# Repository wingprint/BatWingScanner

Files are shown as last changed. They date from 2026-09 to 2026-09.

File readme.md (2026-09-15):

# Bat wing scanner for WingPrint images
This repository contains the code and assembly instructions for the bat wing scanner as described in our WingPrint publication.

Project Website: [https://wingprint.github.io/](https://wingprint.github.io/)

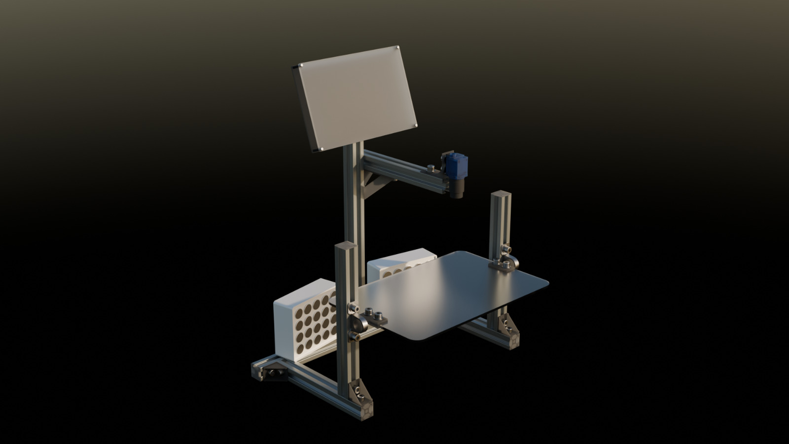
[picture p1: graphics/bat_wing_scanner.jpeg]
Bat wing scanner


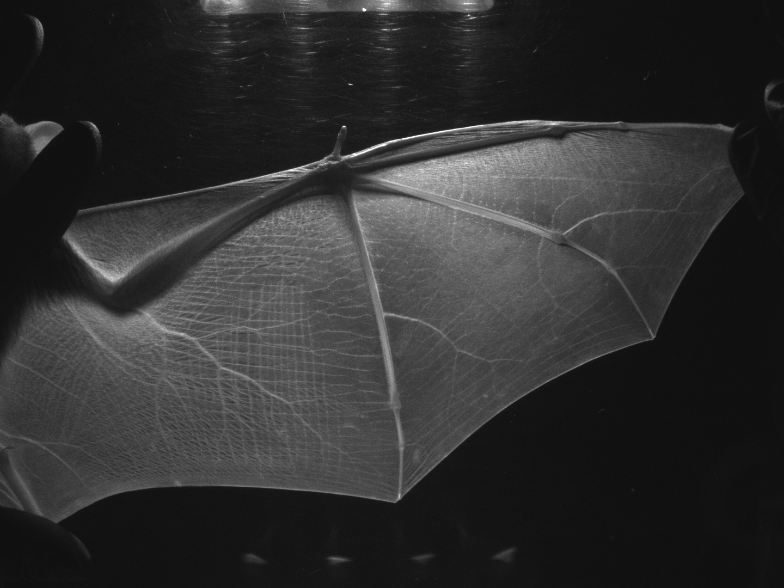
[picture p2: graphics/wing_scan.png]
Wing scan


## Software Installation
This guide describes how to set up the bat wing scanner software on different platforms.

### Platforms
The bat scanner software runs on Linux, Windows (and potentially Mac OS if camera drivers are available). Pi mode can be can be enabled by setting `pi: True` in the configuration file `config.yaml`. This will e.g. enable GPIO features.

We have tested the software on Raspberry Pi 3B+, 4B, and 5 models.

### Cameras
The software works with both industrial cameras and other off-the-shelf cameras like webcams.

If an industrial camera that supports the *GenICam* standard is detected, then that one is used. Otherwise the software tries to pick the next best available camera (e.g. a webcam).

If no camera is detected at all, the software will still run, but show unexpected behaviour in some areas.

### Installation on a Raspberry Pi 3/4/5
Download an image of a recent Raspberry Pi OS 64-bit including the Raspberry Pi Desktop. The following setup has been tested with the Raspberry Pi OS version based on Debian Trixie.

**Optional: Camera driver**

If you want to use an industrial camera that supports the *GenICam* standard, then install a *GenTL producer* from the camera manufacturer. Usually, the manufacturers provide either a complete SDK or a stand-alone GenTL producer.

In our case, we installed a stand-alone GenTL producer from *The Imaging Source* in the form of a Debian package:

`sudo apt install ./gen_tl_producer_arm64.deb`

Afterwards, edit the path to the CTI (Common Transport Interface) file of the driver in the `config.yaml` file. In our case the file is located at:

`cti_path: "/usr/lib/aarch64-linux-gnu/gentl/tis/libic4-gentl-u3v.cti"`

**Note:** The file needs to stay in its original location. Don't copy it somewhere else.

If you don't use an industrial camera, then you shouldn't need to install a camera driver.

**Setting up software framework**

First of all, you need to install some system-wide extensions for PyQT5:

`sudo apt install python3-pyqt5.qtmultimedia python3-pyqt5.qtsvg`

Now, create a Python virtual environment, but with system package access:

`python -m venv --system-site-packages .venv`

and activate it:

`source .venv/bin/activate`

Finally, you can install all necessary dependencies in your virtual environment:

`pip install -r requirements.txt`

**Provide a configuration**

Your `config.yaml` file should look similar to this at this point:

```
machine:
  name: 'Batscanner'
  pi: True
  port: 5000
  cti_path: "/usr/lib/aarch64-linux-gnu/gentl/tis/libic4-gentl-u3v.cti"
camera:
  preview_frame_rate: 30
```

**Launching the bat scanner software**

Run the program with:

`python main.py --production`

The *--production* switch enables fullscreen mode. Run the program without it if you are not on a Raspberry Pi or want to debug the program. In this case, the program will roughly scale to its intended target screen size.

You can access the webserver on the scanner under the address https://127.0.0.1:5000 or via the external IP address of your Raspberry Pi if it is part of a network.

The scan database and all images that you take will be stored inside the `<code_folder>/static/capture/<machine_name>` folder.

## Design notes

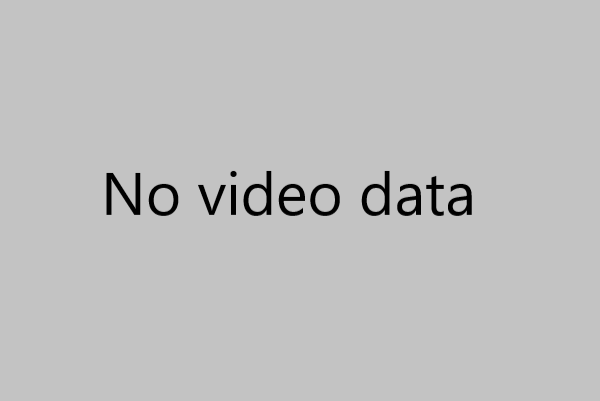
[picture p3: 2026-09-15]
code/graphics/no_video_data.png

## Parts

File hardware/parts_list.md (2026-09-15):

Frame
    aluminium profiles Bosch-type 20x20mm groove 6mm
        1x 530mm
        1x 450mm
        2x 300mm
        3x 250mm
    connectors
        6x Elbow Connector
        12x T-nuts
        12x M4x8mm screws or similar
    screen attachment
        2x M6x20mm screws
        4x M6 washers
        2x M6 wing nuts
        2x M3x10mm screws
        4x M3 washers
        2x M3 nuts
        2x M4x10mm screws
        2x M4 washers
    cantilever attachment
        4x M4x10mm screws
        4x M4 washers
    camera attachment
        2x M6x12mm screws
        2x M4x10mm screws
        2x M4 washers
    plate bearings
        2x Pedestal Bearings
        4x M4x10mm screws
    plate drive
        1x stepper motor 28BYJ-48
        1x motor driver board ULN2003
        1x synchronous wheel drive 20-60T-8B-6 with drivebelt
        6x M4x10mm screws
        6x M4 washers
Acrylic glass plate
    400mm x 250mm with rounded edges
    4x M4x20mm screws
Touchscreen
    Waveshare 10.1inch HDMI LCD
Computer
    1x Raspberry Pi 5 4GB
    1x KKSB Raspberry Pi 5 Case Aluminium Black
    4x M2x8mm screws
Camera
    1x The Imaging Source DMK 33UX273
    1x USB 3.0 Type A to Micro B
    1x Computar A4Z2812CS-MPIR lens
    1x Basler heat sink for ace 2 and racer 2 S (with custom screw holes)
Pedal
    1x Proxxon Footswitch FS

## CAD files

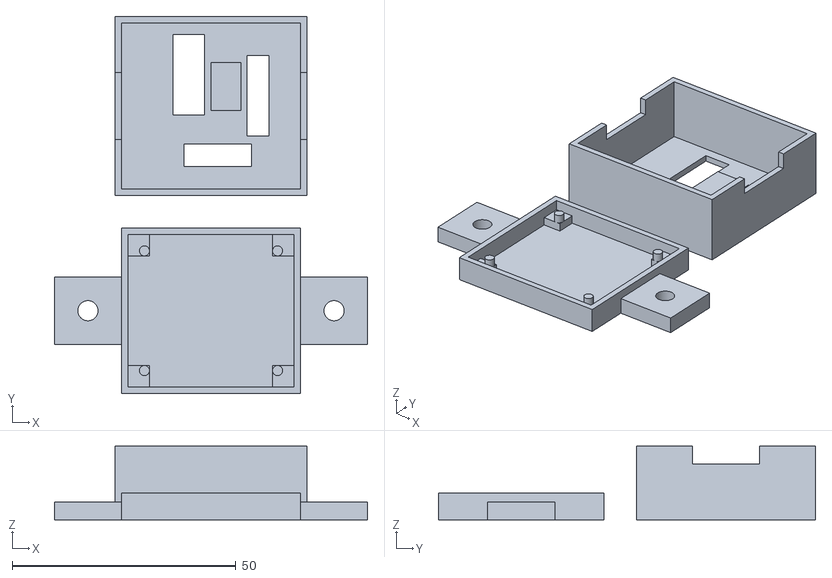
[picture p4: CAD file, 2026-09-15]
hardware/3D_Models/motor_driver_case.stl
70.0 x 84.2 x 16.5

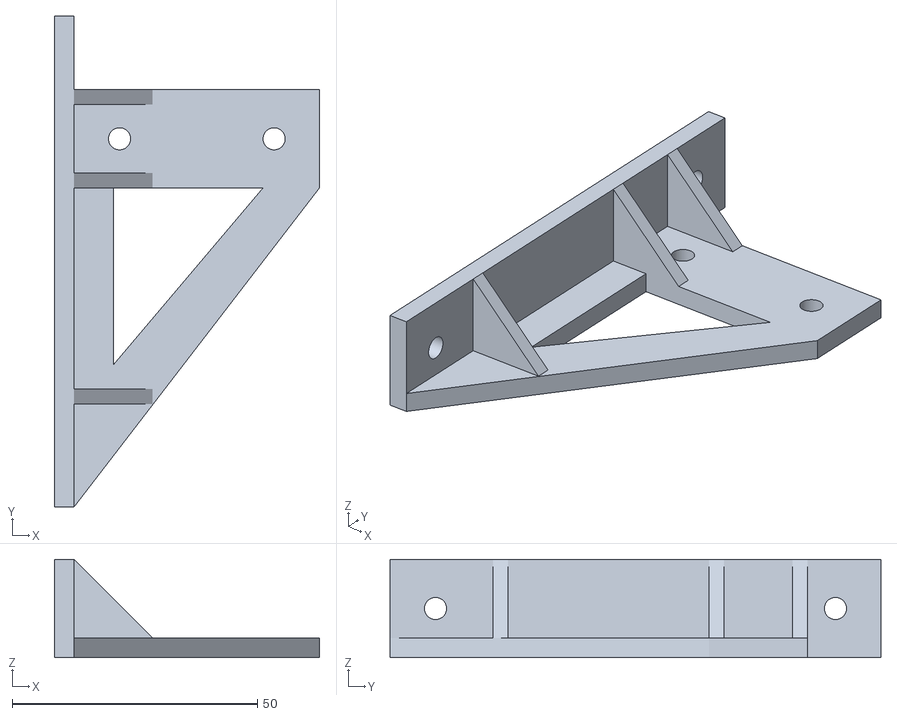
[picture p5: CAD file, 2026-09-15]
hardware/3D_Models/cantilever_attachment.stl
54.0 x 100.0 x 20.0

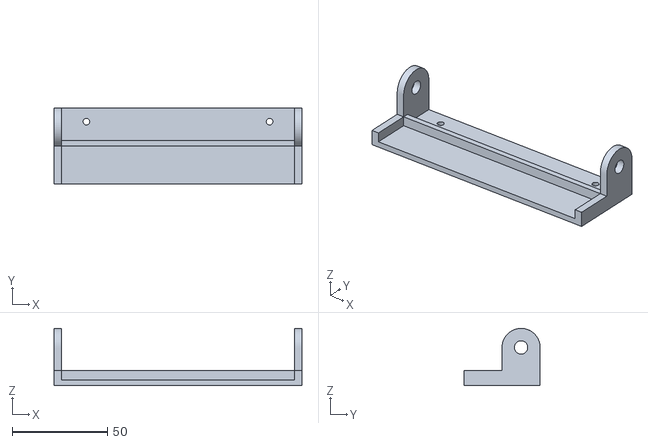
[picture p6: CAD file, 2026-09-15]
hardware/3D_Models/screen_attachment.stl
130.0 x 40.0 x 30.0

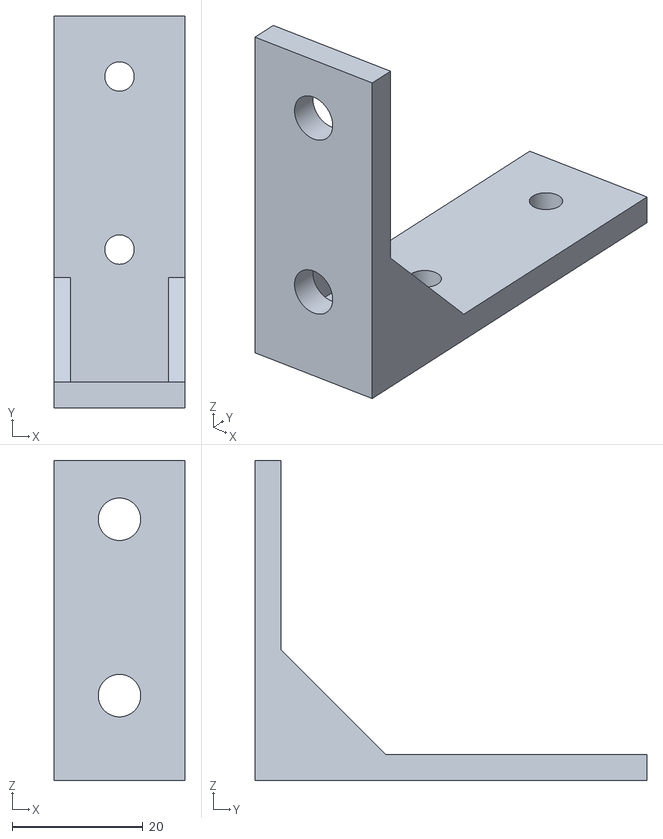
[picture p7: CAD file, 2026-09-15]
hardware/3D_Models/camera_holder_single.stl
20.0 x 60.0 x 49.0

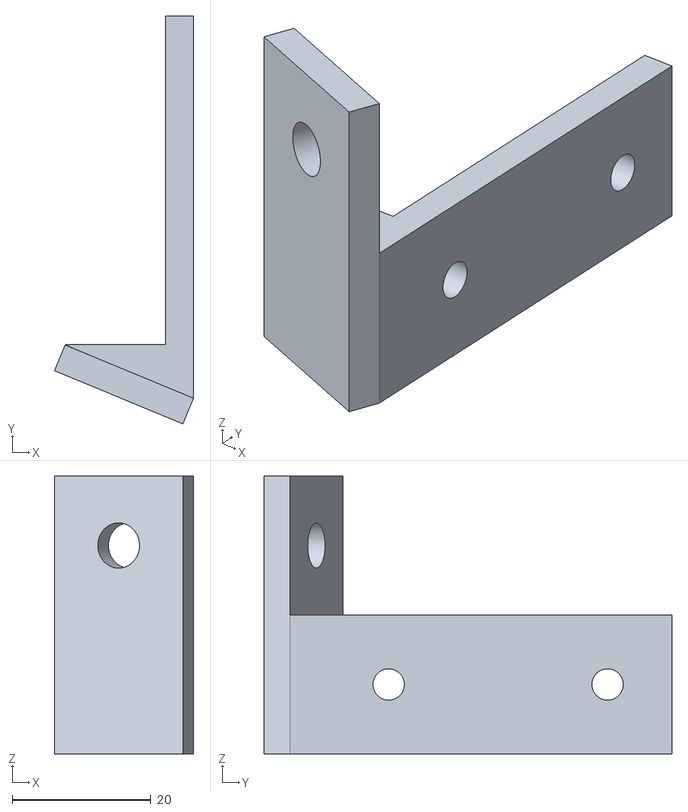
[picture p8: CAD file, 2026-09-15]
hardware/3D_Models/floodlight_holder.stl
20.0 x 58.7 x 40.0

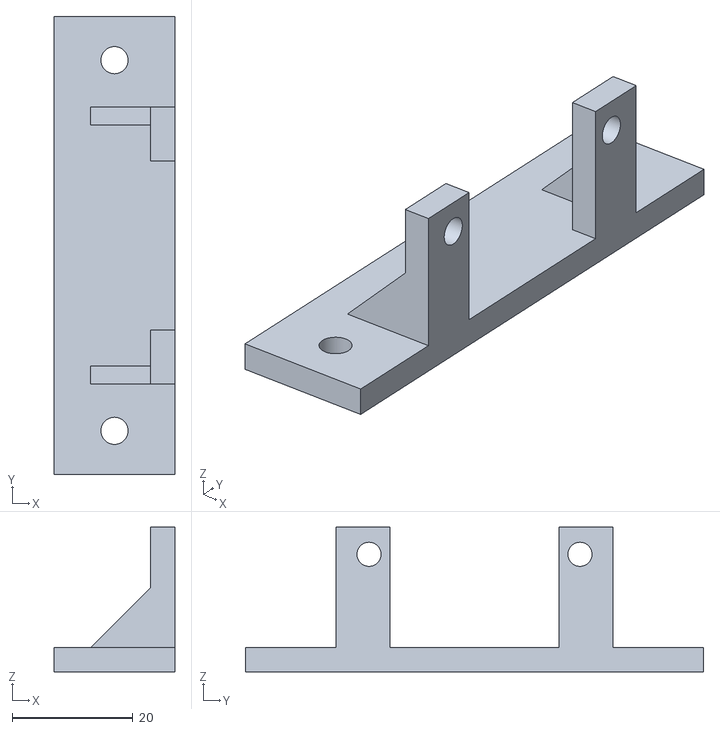
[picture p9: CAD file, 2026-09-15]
hardware/3D_Models/motor_holder.stl
20.0 x 76.0 x 24.0

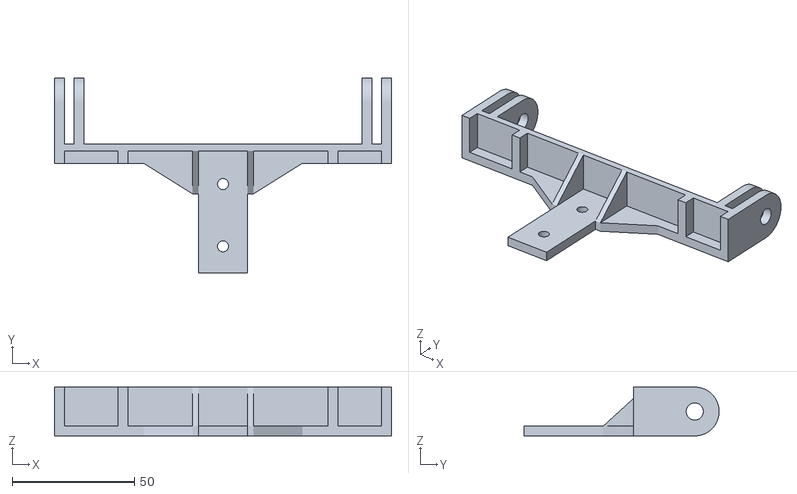
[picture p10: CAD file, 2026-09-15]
hardware/3D_Models/screen_holder.stl
138.0 x 80.0 x 20.0

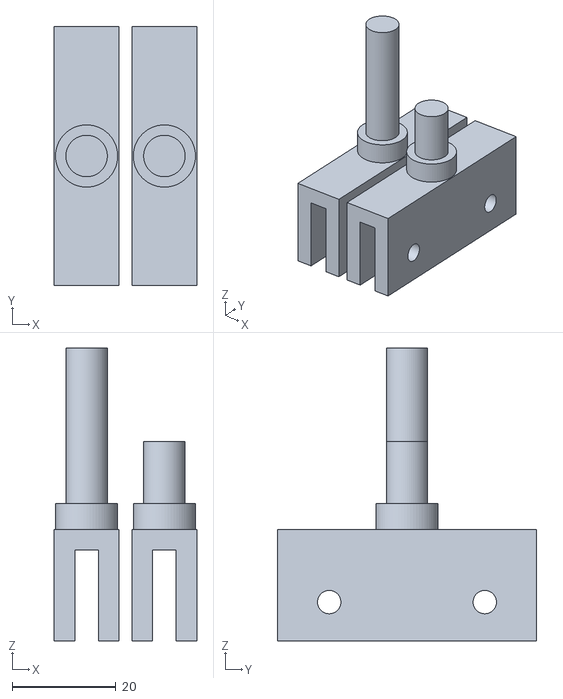
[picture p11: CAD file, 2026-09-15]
hardware/3D_Models/glass_plate_attachments.stl
27.5 x 50.0 x 56.5

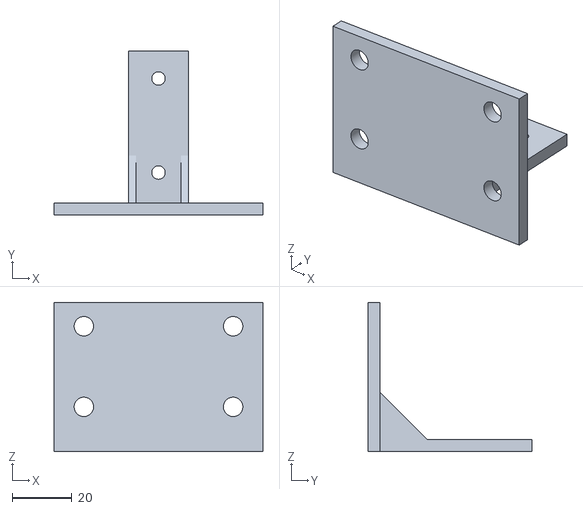
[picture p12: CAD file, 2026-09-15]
hardware/3D_Models/camera_holder_double.stl
70.0 x 55.0 x 50.0

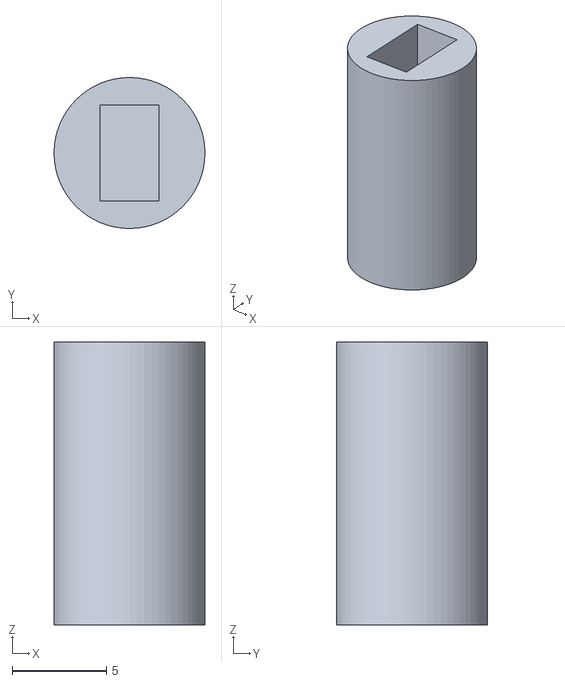
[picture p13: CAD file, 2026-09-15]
hardware/3D_Models/motor_axle.stl
8.00 x 8.00 x 15.0

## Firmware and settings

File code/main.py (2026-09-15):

import argparse
from functools import partial
import cv2
import glob
import numpy as np
import os
from pathlib import Path
import shutil
import time
import yaml
import sys

# Camera
from genicam.gentl import TimeoutException
from harvesters.core import Harvester
from harvesters.util.pfnc import mono_location_formats, rgb_formats, bgr_formats, rgba_formats, bgra_formats

# UI
from PyQt5.QtWidgets import *
from PyQt5.QtMultimedia import *
from PyQt5.QtMultimediaWidgets import *
from PyQt5.QtGui import QPixmap, QImage
from PyQt5.QtCore import Qt, QTimer, QEvent, QObject, QThread, pyqtSignal, pyqtSlot
import qdarktheme

import utils
import camUtils
import hwUtils
import translation

from batServer import ServerThread

from BatServerConnector import BatServerConnector

with open('config.yaml') as f:
    config = yaml.safe_load(f)

if config["machine"]["pi"]:
    from gpiozero import Button

class StepperWorker(QObject):
    finished = pyqtSignal()

    def __init__(self, direction, elevation):
        super(StepperWorker, self).__init__(None)

        self.direction = direction
        self.elevation = elevation

    @pyqtSlot()
    def run(self):
        if self.direction == 0:
            hwUtils.forward(self.elevation)
        else:
            hwUtils.backwards(self.elevation)

        self.finished.emit()

class SaveWorker(QObject):
    imagesSaved = pyqtSignal(Path)

    def __init__(self, images):
        super(SaveWorker, self).__init__(None)

        self.images = images

    @pyqtSlot()
    def run(self):
        folderPath = None

        for path, image in self.images:
            folderPath = Path(path).parent
            os.makedirs(folderPath, exist_ok=True)
            cv2.imwrite(path, image)
        
        self.imagesSaved.emit(folderPath)

class CaptureWorker(QObject):
    updateFeed = pyqtSignal(QImage)
    imageCaptured = pyqtSignal(np.ndarray, QImage)

    def __init__(self, imageAcquirer, cam):
        super(CaptureWorker, self).__init__(None)

        self.imageAcquirer = imageAcquirer
        self.cam = cam

        self.trigger = False
        self.terminate = False

    @pyqtSlot()
    def captureImage(self):
        self.trigger = True

    @pyqtSlot()
    def stopCapturing(self):
        self.terminate = True

    @pyqtSlot()
    def run(self):
        if self.imageAcquirer is not None:
            while not self.terminate:
                try:
                    with self.imageAcquirer.fetch(timeout=1) as buffer:
                        payload = buffer.payload
                        component = payload.components[0]
                        width = component.width
                        height = component.height
                        dataFormat = component.data_format

                        ## This conversion is from the Harvesters documentation ##

                        # Reshape the image so that it can be drawn on the VisPy canvas:
                        if dataFormat in mono_location_formats:
                            frame = component.data.reshape(height, width)
                        else:
                            # The image requires you to reshape it to draw it on the
                            # canvas:
                            if dataFormat in rgb_formats or dataFormat in rgba_formats or dataFormat in bgr_formats or dataFormat in bgra_formats:
                                frame = component.data.reshape(height, width, int(component.num_components_per_pixel))  # Set of R, G, B, and Alpha
                                if dataFormat in bgr_formats:
                                    # Swap every R and B:
                                    frame = frame[:, :, ::-1]

                        frame = frame.copy()

                    h, w, ch = frame.shape
                    bytesPerLine = ch * w

                    convertToQtFormat = QImage(frame.data, w, h, bytesPerLine, QImage.Format_RGB888)
                    p = convertToQtFormat.scaled(utils.VIEWFINDER_WIDTH, utils.VIEWFINDER_HEIGHT, Qt.KeepAspectRatio)

                    if self.trigger:
                        self.imageCaptured.emit(frame, p)

                        self.trigger = False

                    self.updateFeed.emit(p)
                        
                except TimeoutException:
                    continue

        elif self.cam is not None:
            while not self.terminate:
                ret, frame = self.cam.read()

                if ret:              
                    rgbImage = cv2.cvtColor(frame, cv2.COLOR_BGR2RGB)

                    h, w, ch = rgbImage.shape
                    bytesPerLine = ch * w
                    convertToQtFormat = QImage(rgbImage.data, w, h, bytesPerLine, QImage.Format_RGB888)
                    p = convertToQtFormat.scaled(utils.VIEWFINDER_WIDTH, utils.VIEWFINDER_HEIGHT, Qt.KeepAspectRatio)
                    
                    if self.trigger:
                        self.imageCaptured.emit(frame, p)

                        self.trigger = False

                    self.updateFeed.emit(p)

class ControlGrid(QWidget):
    def __init__(self, language, parent=None):
        super(ControlGrid, self).__init__(parent)

        layout = QGridLayout()

        self.externalIndexLabel = QLabel()
        layout.addWidget(self.externalIndexLabel, 0, 0)

        self.externalIndexEdit = QLineEdit()
        self.externalIndexEdit.setMinimumHeight(30)
        self.externalIndexEdit.textEdited.connect(self.flagParamsModified)
        layout.addWidget(self.externalIndexEdit, 0, 1)

        self.bagLabel = QLabel()
        layout.addWidget(self.bagLabel, 1, 0)
        self.bag = QLineEdit()
        self.bag.setMinimumHeight(30)
        self.bag.textEdited.connect(self.flagParamsModified)
        layout.addWidget(self.bag, 1, 1)
        
        self.speciesLabel = QLabel()
        layout.addWidget(self.speciesLabel, 0, 2)
        self.species = QComboBox()
        self.species.setMinimumHeight(30)
        self.species.addItems(species_list)
        self.species.activated.connect(self.flagParamsModified)
        layout.addWidget(self.species, 0, 3)

        self.remarkLabel = QLabel()
        layout.addWidget(self.remarkLabel, 1, 2)
        self.remarks = QLineEdit()
        self.remarks.setMinimumHeight(30)
        self.remarks.textEdited.connect(self.flagParamsModified)
        layout.addWidget(self.remarks, 1, 3)

        self.recaptureBox = QCheckBox()
        self.recaptureBox.stateChanged.connect(self.flagParamsModified)
        layout.addWidget(self.recaptureBox, 0, 4)

        self.maintenanceBox = QCheckBox()
        self.maintenanceBox.stateChanged.connect(self.flagParamsModified)
        layout.addWidget(self.maintenanceBox, 1, 4)
        
        self.saveButton = QPushButton()
        self.saveButton.setMinimumHeight(60)
        self.saveButton.setMinimumWidth(120)
        self.saveButton.setEnabled(False)
        self.saveButton.clicked.connect(
            lambda: parent.save(
                self.remarks.text(), 
                self.externalIndexEdit.text(), 
                self.bag.text(), 
                self.species.currentText(),
                self.recaptureBox.isChecked(),
                self.maintenanceBox.isChecked()
            )
        )
        layout.addWidget(self.saveButton, 0, 5, 2, 1)

        self.next = QPushButton()
        self.next.setMinimumHeight(60)
        self.next.setMinimumWidth(120)
        self.next.clicked.connect(parent.nextAnimal)
        layout.addWidget(self.next, 0, 6, 2, 1)

        self.translate(language)

        self.setLayout(layout)
        self.layout = layout

    def flagParamsModified(self):
        self.saveButton.setEnabled(True)

    def clear(self):
        self.externalIndexEdit.clear()
        self.species.setCurrentIndex(0)
        self.bag.clear()
        self.remarks.clear()
        self.recaptureBox.setChecked(False)
        self.maintenanceBox.setChecked(False)
        self.saveButton.setEnabled(False)
        self.externalIndexEdit.setStyleSheet(None)

    def translate(self, language):
        self.externalIndexLabel.setText(translation.STRINGS["external_id"][language])
        self.speciesLabel.setText(translation.STRINGS["species"][language])
        self.bagLabel.setText(translation.STRINGS["bag"][language])
        self.remarkLabel.setText(translation.STRINGS["remarks"][language])
        self.recaptureBox.setText(translation.STRINGS["recapture"][language])
        self.maintenanceBox.setText(translation.STRINGS["maintenance_data"][language])
        self.saveButton.setText(translation.STRINGS["save"][language])
        self.next.setText(translation.STRINGS["next_animal"][language])

    def setAnimal(self, animal):
        self.externalIndexEdit.setText(animal["foreign_id"])
        self.bag.setText(animal["name"])
        self.remarks.setText(animal["description"])
        self.recaptureBox.setChecked(animal["recapture"])
        self.maintenanceBox.setChecked(animal["maintenance_data"])

        for x in species_dict.keys():
            if species_dict[x] == animal["species_id"]:
                self.species.setCurrentIndex(species_list.index(x))

class StatusGrid(QWidget):
    def __init__(self, language, currentAnimal, parent=None):
        super(StatusGrid, self).__init__(parent)

        layout = QGridLayout()

        self.idLabel = QLabel()
        biggerFont = self.idLabel.font()
        biggerFont.setPointSize(16)
        self.idLabel.setAlignment(Qt.AlignCenter)
        self.idLabel.setFont(biggerFont)
        layout.addWidget(self.idLabel, 0, 0)

        self.diskUsageLabel = QLabel()
        bigFont = self.diskUsageLabel.font()
        bigFont.setPointSize(16)
        self.diskUsageLabel.setAlignment(Qt.AlignCenter)
        self.diskUsageLabel.setFont(bigFont)
        layout.addWidget(self.diskUsageLabel, 0, 1)

        self.statusLabel = QLabel()
        bigFont = self.statusLabel.font()
        bigFont.setPointSize(15)
        self.statusLabel.setAlignment(Qt.AlignCenter)
        self.statusLabel.setFont(bigFont)
        layout.addWidget(self.statusLabel, 1, 0, 1, 2)

        self.setLayout(layout)
        self.layout = layout

        self.update(language, currentAnimal)

    def update(self, language, currentAnimal):
        diskUsage = shutil.disk_usage(os.path.join("static", "capture", config["machine"]["name"]))
        self.diskUsage = int((diskUsage.used/diskUsage.total)*100)
        self.diskUsageLabel.setText(translation.STRINGS['disk_usage'][language].format(int(diskUsage.used/1024/1024/1024), self.diskUsage))
        if self.diskUsage >= utils.STORAGE_WARNING_THRESHOLD:
            self.diskUsageLabel.setStyleSheet("background-color : darkred")
        else:
            self.diskUsageLabel.setStyleSheet(None)

        qrId = currentAnimal["qr_id"]
        self.idLabel.setText(f"{translation.STRINGS['qr_id'][language]}{qrId}")
        if qrId == None or len(qrId) == 0:
            self.idLabel.setStyleSheet("background-color : darkred")
        else:
            self.idLabel.setStyleSheet(None)

class CamControlGrid(QWidget):
    def __init__(self, language, imgIndex, parent=None):
        super(CamControlGrid, self).__init__(parent)

        layout = QGridLayout()

        self.triggerOnce = QPushButton()
        self.triggerOnce.setMinimumHeight(60)
        self.triggerOnce.setMinimumWidth(120)
        self.triggerOnce.clicked.connect(parent.captureImage)
        layout.addWidget(self.triggerOnce, 1, 0, 2, 1)

        self.trigger = QPushButton(f"{translation.STRINGS['picture_sequence'][language]}")
        self.trigger.setMinimumHeight(60)
        self.trigger.setMinimumWidth(150)
        self.trigger.clicked.connect(parent.captureSequence)
        layout.addWidget(self.trigger, 1, 1, 2, 1)

        self.progressBar = None

        self.pictureLabel = QLabel()
        bigFont = self.pictureLabel.font()
        bigFont.setPointSize(16)
        self.pictureLabel.setAlignment(Qt.AlignCenter)
        self.pictureLabel.setFont(bigFont)
        layout.addWidget(self.pictureLabel, 3, 0, 1, 2)

        self.setLayout(layout)
        self.layout = layout

        self.update(language, imgIndex, None)

    def update(self, language, imgIndex, progress):
        if progress is not None:
            if self.progressBar:
                if progress/hwUtils.FRAMES_PER_SEQUENCE == 1:
                    self.progressBar.setFormat(translation.STRINGS["saving_images"][language])
                else:
                    self.progressBar.setFormat(f"{translation.STRINGS['scanning'][language]}")
                self.progressBar.setValue(int(100*(progress/hwUtils.FRAMES_PER_SEQUENCE)))
            else:
                self.trigger.setEnabled(False)
                self.trigger.setVisible(False)
                self.triggerOnce.setEnabled(False)
                self.progressBar = QProgressBar()
                self.progressBar.setMinimumHeight(60)
                self.progressBar.setMinimumWidth(150)
                if progress/hwUtils.FRAMES_PER_SEQUENCE == 1:
                    self.progressBar.setFormat(translation.STRINGS["saving_images"][language])
                else:
                    self.progressBar.setFormat(f"{translation.STRINGS['scanning'][language]}")
                self.progressBar.setValue(int(100*(progress/hwUtils.FRAMES_PER_SEQUENCE)))
                self.layout.replaceWidget(self.trigger, self.progressBar)
        else:
            if self.progressBar:
                self.layout.replaceWidget(self.progressBar, self.trigger)
                self.progressBar.deleteLater()
                self.progressBar = None
                self.trigger.setEnabled(True)
                self.trigger.setVisible(True)
                self.triggerOnce.setEnabled(True)

        self.pictureLabel.setText(f"Pictures taken: {imgIndex}")
        if imgIndex == 0:
            self.pictureLabel.setStyleSheet("background-color : darkgreen")
        else:
            self.pictureLabel.setStyleSheet(None)

        self.triggerOnce.setText(translation.STRINGS["one_photo"][language])
        self.trigger.setText(translation.STRINGS["picture_sequence"][language])

class CamSettingsDialog(QDialog):
    def __init__(self, language, exposureTime, gain, camTemperature, parent=None):
        super().__init__(parent)

        self.setWindowTitle(translation.STRINGS["camera_settings"][language])

        dialogButtons = QDialogButtonBox.Ok | QDialogButtonBox.Cancel

        self.buttonBox = QDialogButtonBox(dialogButtons)
        self.buttonBox.button(QDialogButtonBox.Ok).setText(translation.STRINGS["ok"][language])
        self.buttonBox.button(QDialogButtonBox.Cancel).setText(translation.STRINGS["cancel"][language])
        self.buttonBox.accepted.connect(self.accept)
        self.buttonBox.rejected.connect(self.reject)

        self.layout = QVBoxLayout()
        
        self.layout.addWidget(QLabel(translation.STRINGS["exposure_time"][language]))
        self.exposureEdit = QLineEdit(str(exposureTime))
        self.layout.addWidget(self.exposureEdit)

        self.layout.addWidget(QLabel(translation.STRINGS["gain"][language]))
        self.gainEdit = QLineEdit(str(gain))
        self.layout.addWidget(self.gainEdit)

        self.layout.addWidget(QLabel(f"{translation.STRINGS['temperature'][language]}: {camTemperature:.2f} °C"))

        self.layout.addWidget(self.buttonBox)
        self.setLayout(self.layout)
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

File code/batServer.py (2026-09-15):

import os
import argparse
import pandas as pd

import datetime
from PIL import Image

from flask import Flask, request, render_template, jsonify, flash, redirect, url_for, send_from_directory
from flask_sqlalchemy import SQLAlchemy
import shutil
import threading
import urllib3
import yaml

from PyQt5.QtCore import QObject, pyqtSignal

urllib3.disable_warnings(urllib3.exceptions.InsecureRequestWarning)

app = Flask(__name__)
app.secret_key = "Bruce Wayne is Batman"

with open('config.yaml') as f:
    config = yaml.safe_load(f)

# DB Stuff
os.makedirs(f"{app.root_path}/static/capture/{config['machine']['name']}/", exist_ok=True)
app.config['SQLALCHEMY_DATABASE_URI'] = f"sqlite:///{app.root_path}/static/capture/{config['machine']['name']}/batcave_{config['machine']['name']}.sqlite"
app.config['machinename'] = config['machine']['name']
db = SQLAlchemy(app)


# --------------------------------------------------------------------------------------
# Classes
# --------------------------------------------------------------------------------------
class Species(db.Model):
    id = db.Column(db.Integer, primary_key=True)
    name = db.Column(db.String(50), nullable=False)
    description = db.Column(db.String(200))
    animals = db.relationship("Animal", backref='species', lazy=True)

    def __lt__(self, other):
        return self.name < other.name

    def __eq__(self, other):
        return self.name == other.name

    def __json__(self):
        return {
            "id": self.id,
            "name": self.name,
            "description": self.description,
        }


class Animal(db.Model):
    # from DB always unique
    id = db.Column(db.Integer, primary_key=True)
    # In case the Smithonians use a different ID
    foreign_id = db.Column(db.String(50))
    # from the QR code
    qr_id = db.Column(db.String(50))
    # For interesting individuals
    name = db.Column(db.String(50))
    # timestamp
    created = db.Column(db.DateTime, default=lambda: datetime.datetime.now(datetime.timezone.utc))
    # in case something is important
    description = db.Column(db.String(200))
    # which bat species
    species_id = db.Column(db.Integer, db.ForeignKey('species.id'), nullable=True)
    recapture = db.Column(db.Boolean, nullable=False, default=0)
    maintenance_data = db.Column(db.Boolean, nullable=False, default=0)
    recapture_foreign_id = db.Column(db.Integer)
    location = db.Column(db.String(50))

    def __lt__(self, other):
        return self.id < other.id

    def __eq__(self, other):
        return self.id == other.id
    
    def __json__(self):
        return {
            "id": self.id,
            "name": self.name,
            "description": self.description,
            "foreign_id": self.foreign_id,
            "qr_id": self.qr_id,
            "species_id": self.species_id,
            "recapture": self.recapture,
            "maintenance_data": self.maintenance_data
        }


# --------------------------------------------------------------------------------------
@app.route('/')
def home():
    # Render the template with the title parameter
    return render_template('index.html', title='Batscanner')


# --------------------------------------------------------------------------------------
# Species
# --------------------------------------------------------------------------------------
@app.route('/species')
def species():
    species = sorted(Species.query.all())
    return render_template('species.html', species=species)

# --------------------------------------------------------------------------------------
# Animals
# --------------------------------------------------------------------------------------
@app.route('/animals')
def animals():
    animals = sorted(Animal.query.all())
    return render_template('animals.html', animals=animals)


@app.route('/animals/add', methods=['GET'])
def add_animals_form():
    species = sorted(Species.query.all())
    return render_template('animals_add.html', species=species)


@app.route('/animals/add', methods=['POST'])
def add_animals():
    name = request.form['name']
    species_id = request.form['species_id']
    description = request.form['description']

    if not name:
        flash('Name is required.', 'danger')
        return redirect(url_for('add_animals_form'))

    new_animal = Animal(name=name, description=description, species_id=species_id)
    db.session.add(new_animal)
    db.session.commit()

    flash('Animal added successfully!', 'success')
    return redirect(url_for('animals'))


@app.route('/animals/qr', methods=['GET'])
def get_qr():
    return render_template('qr.html')

@app.route('/animals/qr/<string:qr_id>', methods=['GET'])
def redirect_animal_qr(qr_id):
    animal = Animal.query.filter_by(qr_id=qr_id).first()
    if animal is not None:
        return redirect(url_for('edit_animals_form', animal_id=animal.id))
    else:
        flash('No such animal', 'warning')
        return redirect(url_for('get_qr'))


@app.route('/animals/edit/<int:animal_id>', methods=['GET'])
def edit_animals_form(animal_id):
    animal = Animal.query.get_or_404(animal_id)
    species = sorted(Species.query.all())
    return render_template('animals_edit.html', animal=animal, species=species)


@app.route('/animals/edit/<int:animal_id>', methods=['POST'])
def edit_animals(animal_id):
    animal = Animal.query.get_or_404(animal_id)

    animal.species_id = request.form["species_id"]
    animal.foreign_id = request.form['foreign_id']
    animal.qr_id = request.form['foreign_id']
    animal.name = request.form['name']

    if request.form.get('recapture') and request.form['recapture'] == "on":
        animal.recapture =  True
    else:
        animal.recapture =  False

    if request.form.get('maintenance_data') and request.form['maintenance_data'] == "on":
        animal.maintenance_data =  True
    else:
        animal.maintenance_data =  False

    animal.description = request.form['description']
    db.session.commit()

    # Send the changes to the QT Window
    animal_last = Animal.query.order_by(Animal.id.desc()).first()
    if animal_last.id == animal_id:
        species = Species.query.get_or_404(animal.species_id)
        app.config["self"].animalChanged.emit(animal.__json__(), species.name)

    flash('Animal updated successfully!', 'success')
    return redirect(url_for('animals'))


@app.route('/animals/editlast', methods=['GET'])
def edit_animals_last_form():
    animal = Animal.query.order_by(Animal.id.desc()).first()
    species = sorted(Species.query.all())
    return render_template('animals_edit.html', animal=animal, animal_id=animal.id, species=species)
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
